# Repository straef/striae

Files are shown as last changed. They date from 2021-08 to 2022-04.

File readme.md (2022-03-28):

# striae layout & project build
a full-size plus ortholinear keyboard project designed for myself

### stria `(noun) \ 'strī-ə \`
_plural_ `striae \ 'strī-,ē \` \
: a stripe or line distinguished from the surrounding area by color, texture, or elevation

## Contributors
[PandLantis](https://github.com/PandLantis) \
[Nabber](https://github.com/DKH707)

## Background & Process

This project started just because I wanted a keyboard that suited me. I have always been confused by the offset on modern keyboards and confounded at its persistence after learning why it was done. Additionally, as I used traditional fullsize keyboards I was bothered by how far I had to move my right hand to go between the mouse and the home row. Further frustrations arose from wanting to use the numpad and the mouse at the same time. I downsized to a TKL keyboard and that ameliorated the distance problem somewhat, but added a new problem of wanting a numpad and not having one. I made an autohotkey script to be able to toggle my number row to send numpad inputs, but it is not the same.

**…so, I knew I wanted**:
- a numpad, but not on the right
	- Might as well move the nav cluster (arrows, page up, page down, home, end, insert, delete) while I am at it.
	- This also mirrors the convention of having directional input (d-pad) under the left hand from all video game controllers I am aware of.
- ortholinear because _logic_
	- Ortholinear layouts are generally praised by those that switch to them (sample bias) and I like the look of them more.
- probably not qwerty because _also logic_
	- The qwerty layout worked for its intended purpose, but may not be best suited to my use, or modern keyboard inputs generally. With functionally no downside to testing a different layout other than the time spent, why not explore different options?

I started to look around for something that suited me but I ended up coming up short[^1]. The mechanical keyboard community is vast, varied, and beautiful; but most members are into smaller boards and by far the most common differentiators on keyboards are switches and keycaps. Which is great! I love a pretty board, but I also need something functional for me. That is how I define beauty.

I started building a layout for myself on [keyboard-layout-editor](http://www.keyboard-layout-editor.com). While I was building, I started looking into arrangements other than qwerty, as well. After going through plenty of revisions I started researching how I was going to be able to make the functionality I wanted possible. That is how I found [quantum mechanical keyboard](https://github.com/qmk/qmk_firmware) firmware, or QMK. QMK seemed like it could do what I wanted and I just had to learn how to use it. At this point I began to give serious consideration to the actual production of the physical keyboard. I started looking for and testing out switches, picking materials. I needed to make some decisions about the case and I did not like having a simple sandwich board, with or without the middle layers. Since everything else is from scratch I might as well learn a cad software and design my own case, so I did. During the process of doing all the design work my brother, an electrical engineer, offered to make a pcb design so he could practice. Seemed interesting to me so I took him up on it.

After completing the designs and selecting the switches and keycaps, I went about having the PCB made and purchased the components.

**suppliers I used and would recommend**:
- [digikey]\: electrical and machine parts (bom available in folders)
- [jlcpcb]\: pcb manufacture
- [bert rabbe]\: local woodworker to make the case frame
- [laserboost]\: plates
- [zealpc]\: zilent v2 62g for the office keyboard
- [ringerkeys]\: boba u4 silent 62g for the home keyboard (i am making two)
- [divinikey]\: np pbt milkwhite blanks (home) and millmax hotswap sockets
- [kbdfans]\: dsa blanks kit 17 (work)
- [weact studio]\: weact blackpill v3 stm32f411ceu6
	- find links to their official store on the product page
- [keygem]\: switch sampler
- [signature plastics]\: dsa 2u pos keycaps

_I think that is all of them. If I remember or add any more I will be sure to list them here_

## technical stuff
_this is ugly and a brain dump. will be cleaned up, maybe._ \
qmk firmware, ~~vial integration~~ qmk-xap is end goal for keyboard management through software. Initial firmware will not have any via(l) integration, but may use vial if xap does not get to workable state soon enough. \
119 keys, full size keyboard plus. split out some 2u keys on the numpad, split spacebar, added two columns between the hands. see ideal keyboard layout file for kle data. \
matrix is 12rows × 10 columns. the nav cluster is a single column in the matrix, every other matrix column is made from two adjacent physical columns. \
2 is31fl3733 led drivers control per-key rgb leds. \
all components are surface mount, except the mcu which is intentionally distinct from the matrix pcb for modularity. \

**VendorID: 0x0010** - Why did I choose this? This is not otherwise registered (according to [device hunt](https://devicehunt.com)) but cannot remember the reason I selected this id to occupy. Probably because if taken as digit pairs it is "0 2" in base10, which is a pun on the name of the "company" (nihilad) that I use to make things in my head canon. \
**ProductID: 0x0110** - I chose this because the double 1s look like lines which is the name of the board. \

[^1]: There are definitely options out there that do some of things I want (e.g. [southpaw-keyboard](https://ludovic.chabant.com/devblog/2018/07/24/southpaw-keyboard/)).

[digikey]:https://www.digikey.com
[jlcpcb]:https://jlcpcb.com
[bert rabbe]:http://beraht.com/index.html
[laserboost]:https://www.laserboost.com
[zealpc]:https://zealpc.net
[ringerkeys]:https://ringerkeys.com
[divinikey]:https://divinikey.com
[kbdfans]:https://kbdfans.com
[weact studio]:https://github.com/WeActTC/MiniSTM32F4x1
[keygem]:https://keygem.store
[signature plastics]:https://pimpmykeyboard.com

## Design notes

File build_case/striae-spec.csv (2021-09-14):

switch	pcb	plate	form	case
14	404.812	408.812	417.312	0.5						underline	arbitrary
14	114.3	118.3	126.8	4						italic	externally fixed
5	1.5	1.5	16							bold	calculated
19.05	404.812	2	3
	114.3	2.38125	6
	1.5	0	4
6
21

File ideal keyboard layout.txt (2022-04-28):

v3.7w
[{fa:[0,0,1],x:1},"print screen","scroll lock","pause",{x:0.125},"caps lock",{x:1,n:true},"esc",{x:0.125},"","f1","f2","f3","f4","f5","f6","f7","f8","f9","f10","f11","f12",""],
["num lock","n-","n+","n×",{x:0.125},"ins","pgUP","del",{x:0.125},"`","1","2","3","4","5","-","=","6","7","8","9","0","\\"],
["n÷","n7","n8","n9",{x:0.125},"home",{n:true},"pgDN","end",{x:0.125},"tab","q","d","r","w","b","[","]","j","f","u","p","'",";"],
["n=","n4",{n:true},"n5","n6",{x:3.25},"back space","h","s","a",{n:true},"t","g","lsft_t(","rsft_t)","y",{n:true},"n","e","o","i","enter"],
["nEnter","n1","n2","n3",{x:1.125},"up",{x:1.125},"lshift","z","x","m","c","v","lctl_t<","rctl_t>","k","l",",",".","/","rshift"],
["tab","back space","n.","n0",{x:0.125},"left",{n:true},"down","right",{x:0.125},"","lctrl","winc","lgui","lalt",{w:2},"",{w:2},"","ralt","rgui","app","rctrl",""]

v3.4pins
[{x:1},	"","","",{x:0.125},	"",	{x:1},"",	{x:0.125},"","","","","","","","","","","","","",""],
["",		"","","",{x:0.125},	"",	"",		"",	{x:0.125},"","","","","","","","","","","","","",""],
["",		"","","",{x:0.125},	"",	"",		"",	{x:0.125},"","","","","","","","","","","","","",""],
["",		"","","",{x:3.25},													"","","","","","","","","","","","","",""],
["",		"","","",{x:1.125},			"",				{x:1.125},"","","","","","","","","","","","","",""],
["",		"","","",{x:0.125},	"",	"",		"",	{x:0.125},"","","","","","","","","","","","","",""]

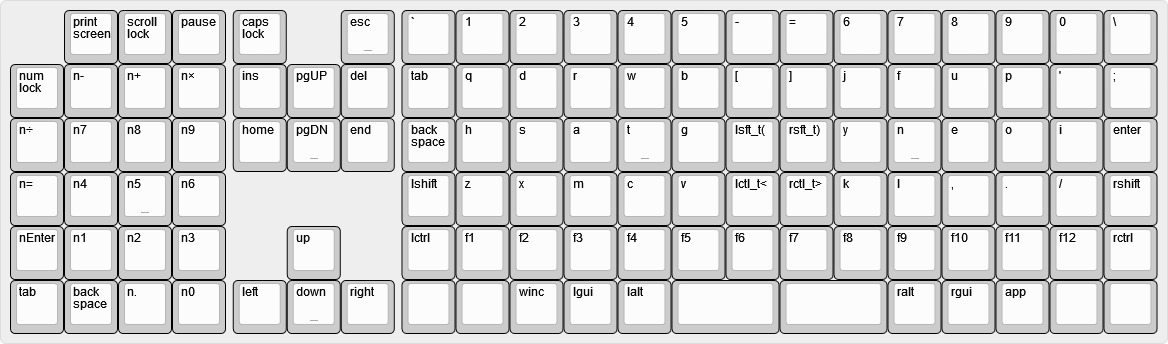
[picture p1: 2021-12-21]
photos/keyboard-layout.jpg

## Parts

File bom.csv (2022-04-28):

bom
https://www.digikey.com/short/wn8fm2b9
Reference | Quantity | Value | Footprint | Datasheet | Description | Height | Manufacturer_Name | Manufacturer_Part_Number | Mouser Part Number | DigiKey Part Number | Mouser Price | DigiKey Price
C1 C3 C5 C7 C10 C12 C14 C16 C19 C20 | 10 | 0.47u | Capacitor_SMD:C_1206_3216Metric_Pad1.33x1.80mm_HandSolder |  |  |  | Samsung Electro-Mechanics | CL31B475KAHNFNE |  | 1276-3177-1-ND |  | $0.159
C2 C4 C6 C8 C11 C13 C15 C17 | 8 | 0.1u | Capacitor_SMD:C_1206_3216Metric_Pad1.33x1.80mm_HandSolder | ~ |  |  | KEMET | C1206C104K3RACTU |  | 399-8140-1-ND |  | $0.086
C9 C18 | 2 | 22u | Capacitor_SMD:C_1206_3216Metric_Pad1.33x1.80mm_HandSolder | ~ |  |  | KEMET | T491A226K006AT |  | 399-8279-1-ND |  | $0.490
D1-D119 | 119 | DIODE | Diode_SMD:D_SOD-123 | ~ |  |  | Nexperia USA Inc. | PMEG2005EGWX |  | 1727-7329-1-ND |  | $0.130
IC1 IC2 | 2 | IS31FL3733-QFLS4-TR | LED-Driver:QFN40P600X600X80-49N-D | http://www.issi.com/WW/pdf/31FL3733.pdf | IC LED DRVR LINEAR 46MA 48QFN | 0.8 | Lumissil | IS31FL3733-QFLS4-TR | 870-31FL3733QFLS4TR | 2521-IS31FL3733B-QFLS4-CT-ND |  | $3.090
J1 | 1 | Conn_01x40 | Connector_PinHeader_1.00mm:PinHeader_1x40_P1.00mm_Horizontal | ~ |  |  | Chip Quik Inc. | HDR100MET40M-G-RA-TH |  | HDR100MET40M-G-RA-TH-ND |  | $1.590
LED2 LED3 LED4 LED5 LED7 LED8 LED9 LED10 LED11 LED12 LED13 LED14 LED15 LED16 LED17 LED18 LED19 LED20 LED21 LED22 LED23 LED24 LED25 LED26 LED27 LED28 LED29 LED30 LED31 LED32 LED33 LED34 LED35 LED36 LED37 LED38 LED39 LED40 LED41 LED42 LED43 LED44 LED45 LED46 LED47 LED48 LED49 LED50 LED51 LED52 LED53 LED54 LED55 LED56 LED57 LED58 LED59 LED60 LED61 LED62 LED63 LED64 LED65 LED66 LED67 LED71 LED72 LED73 LED74 LED75 LED76 LED77 LED78 LED79 LED80 LED81 LED82 LED83 LED84 LED85 LED86 LED87 LED88 LED90 LED92 LED93 LED94 LED95 LED96 LED97 LED98 LED99 LED100 LED101 LED102 LED103 LED104 LED105 LED106 LED107 LED108 LED109 LED110 LED111 LED112 LED113 LED114 LED115 LED116 LED117 LED118 LED119 LED120 LED121 LED122 LED123 LED124 LED125 LED126 | 119 | XZMDKCBDDG45S-9 | Reverse-Mount-RGB:XZMDKCBDDG45S9 | http://www.sunledusa.com/products/spec/XZMDKCBDDG45S-9.pdf | LED RGB CLEAR 4SMD GW | 2.1 | SunLED | XZMDKCBDDG45S-9 |  | 1497-1257-1-ND |  | $0.543
R1 R4 R5 | 3 | 100K | Resistor_SMD:R_1206_3216Metric_Pad1.30x1.75mm_HandSolder | ~ |  |  | Bourns Inc. | CR0805AFX-1003ELF |  | 118-CR0805AFX-1003ELFCT-ND |  | $0.100
R2 R3 | 2 | 2K | Resistor_SMD:R_1206_3216Metric_Pad1.30x1.75mm_HandSolder | ~ |  |  | Bourns Inc. | CR0402AFX-2001GLF |  | 118-CR0402AFX-2001GLFCT-ND |  | $0.037
R6 R7 | 2 | 20K | Resistor_SMD:R_1206_3216Metric_Pad1.30x1.75mm_HandSolder | ~ |  |  | Vishay Dale | CRCW060320K0FKEB |  | 541-CRCW060320K0FKEBCT-ND |  | $0.038

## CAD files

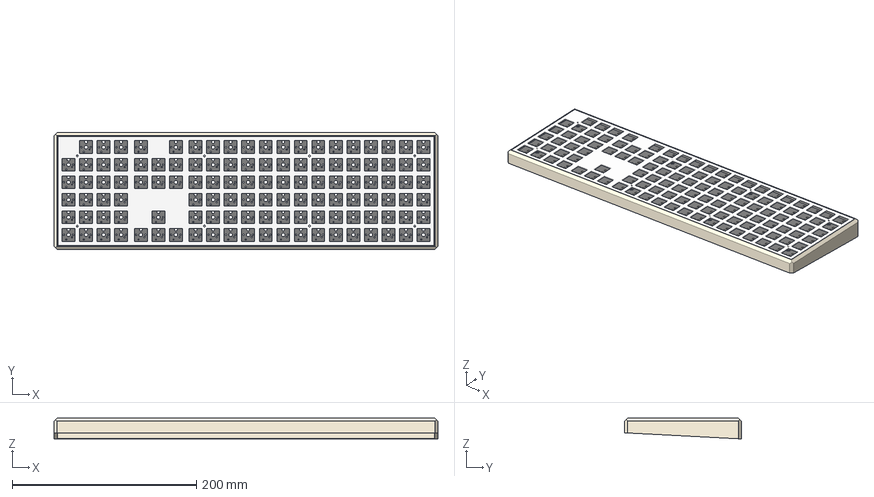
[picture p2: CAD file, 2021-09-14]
build_case/striae.FCStd
417.3 x 126.8 x 22.6 mm
case
plate
base
strutX.01
strutX.02
strutY.02
strutY.03

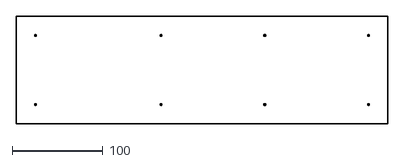
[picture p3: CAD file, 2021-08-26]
build_case/striae-base.dxf
408.8 x 118.3

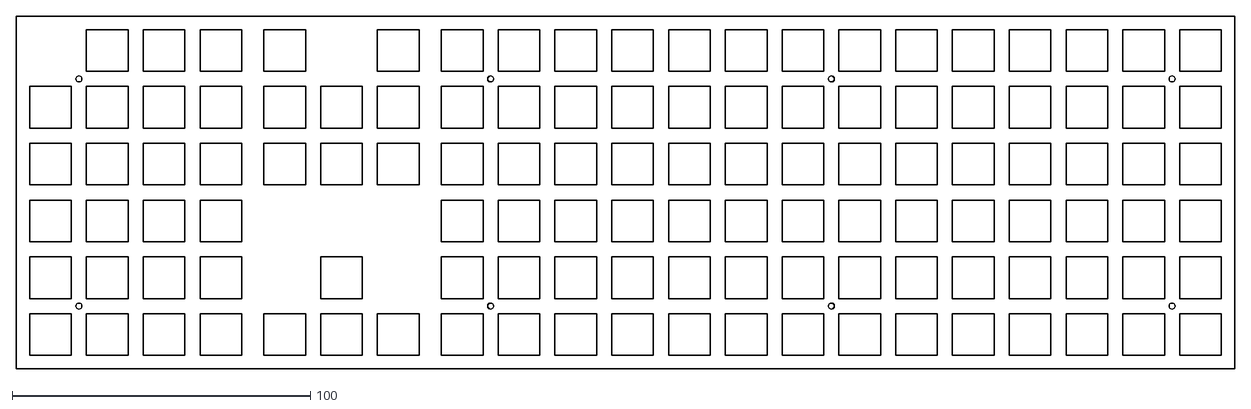
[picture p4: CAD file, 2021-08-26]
build_case/striae-plate.dxf
408.8 x 118.3

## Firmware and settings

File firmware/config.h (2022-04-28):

//copyright 2021 straef <straef@nihilad.com>

#pragma once

//#define VENDOR_ID               0x0010
//#define PRODUCT_ID              0x0110
#define DEVICE_VER              0x0000

#define MANUFACTURER            hexRAVEN_labs
#define PRODUCT                 striae_r00
#define DESCRIPTION             the striae r00 by hexRaven_labs is a fullsize plus ortholinear keyboard with a left-side numpad and nav cluster

#define MATRIX_COLS             10
#define MATRIX_ROWS             12

#define MATRIX_COL_PINS         { C13, C14, C15, A0, A1, A2, A3, A4, A5, A6 }
#define MATRIX_ROW_PINS         { A7, B0, B1, B12, B13, B14, B15, A8, A15, B3, B4, B5 }
#define UNUSED_PINS             { B2, B10, A9, A10, A11, A12, B6, B7, B8, B9 }

#define DIODE_DIRECTION         COL2ROW

/*
 * Feature disable options
 *  These options are also useful to firmware size reduction.
 */

/* disable debug print */
//#define NO_DEBUG

/* disable print */
//#define NO_PRINT

/* disable action features */
//#define NO_ACTION_LAYER
//#define NO_ACTION_TAPPING
//#define NO_ACTION_ONESHOT

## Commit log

2021-06-05 initial commit - current status: rough cad model created, will need to be modified based on communication with machinist; switch layout very firm; keymap for base (default layer) mostly likely firm; 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
    [striae.FCStd]
2021-06-05 revising model to fit with new assembled box approach WIP
    [striae.FCStd]
2021-06-17 design complete, waiting on dimension from pcb. increased wall-thickness. removed bottom wooden wall in favor of the bottom plate only.
    [striae.FCStd, striae_base.FCStd, striae_plate.FCStd]
2021-06-17 removed separate plate files because they lagged behind the master design requiring extra upkeep, and were not up to date with the correct dimensions.
    [striae_base.FCStd, striae_plate.FCStd]
2021-06-18 incorporating submodules for kicad libraries into project
2021-06-21 modifications to the library submodules. tracking kicad files.
    [striae.FCStd, striae.kicad_pcb, striae.sch]
2021-08-26 add final gerber and step files. update cad with changes to struts accommodating surface mounted components. update gitignore. remove submodule. remove pcb design files. restructure folders.
    [striae-base.dxf, striae-plate.dxf, striae.FCStd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]
2021-09-14 update ignore. add spec. update cad. update layout to 3.5w.
    [striae-spec.csv, striae.FCStd]
2021-09-26 directory name change. progress on completing required files for building qmk.
    [layout-info.csv]
2021-10-01 initialize bill of materials
    [bom.csv]
2021-11-15 Capitalization and grammar edit
    First pass on the Readme. Capitalized and edited some sentences to keep the intent intact while improving flow.
2022-01-31 fixed incorrect swap of brackets and parenthesis in contributors
2022-03-29 compilable flashable, cannot reset
    [config.h]
2022-04-12 notes on the pcb matrix and labels mapping to pins
2022-04-28 getting the basest keymap and layout to compile and flash onto the controller using the correct pin assignments and testing that it works.
    [config.h]
2022-04-28 updating bill of materials
    [bom.csv]
2022-04-28 notes on pcb to figure out where things need to go and remember where i put them. updated ideal layout seems more comfortable to have function row above rest.
